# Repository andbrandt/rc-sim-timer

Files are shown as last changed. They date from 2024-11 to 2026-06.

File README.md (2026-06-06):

rc-sim-timer
===
Project to manage RC Flight Simulators via an Arduino-based push button UI.



Currently supported RC FLight Simulators:

* Phoenix v4
* RealFlight Basic
* RealFlight v9

    Note: This project uses git submodules.

    To clone this project use these commands:

    * git clone https://github.com/andbrandt/rc-sim-timer
    * cd rc-sim-timer
    * git submodule init
    * git submodule update

---
# Features:

* Pushbutton to reset simulation when plane gets too far away - or crashes
* Countdown on 7 segment display to show remaining time
* Flashing of 7 segment display when time is running out
* Cool-down period (8 seconds) to nudge current user to hand over controller to next person
* Long-press to select actual RC Simulator and simulation time of 2, 5 or 10 minutes
* Double-press to toggle between EASY and ACRO models

---
# How to start up system:

1. Start up Windows and log in
2. Connect USB RC controller to the front port of the sim-timer box
3. Connect the sim-timer box cable

---
# User Interface:

## Push button
* <b>Light in button</b>: Simulation ready to run - or running. 
* <b>Short-press</b>: Reset simulation
* <b>Double-press</b>: Toggle between EASY and ACRO models
* <b>Long-press</b>:  Enter Setup menu to select RC Simulator and simulation time.
  * Short-press while in Setup: Toggle selection
  * Long-press while in Setup: Accept current selection; then step to next setting or exit setup
* <b>Press during power-op</b>: SAFE MODE:
USB Keyboard/mouse inactivated to not interfere with firmware update

## 7-segment display
* Shows remaining simulation time
* In Setup menu, the display steps through options to be selected

---
# Simulator preparation
Depending on your simulator, you may have to do a litte setup to make it work with rc-sim-timer.
## Phoenix v4
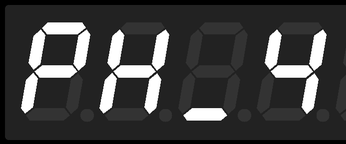
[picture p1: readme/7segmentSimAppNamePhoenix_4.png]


Define two airplane favorites in the aircraft setup menu. Let the first (uppermost) be an electric high-wing beginner model and the second be an aerobatic model.

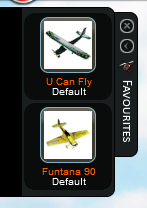
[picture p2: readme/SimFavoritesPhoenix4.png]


rc-sim-timer starts up the simulator when the USB plug is inserted.

TODO: Update code to select desired airport when starting.

TODO: Update code to select desired airplanes for easy and acro without requiring sim setup.

rc-sim-timer will choose an airplane from this list when you toggle between models using double press.
## RealFlight Basic
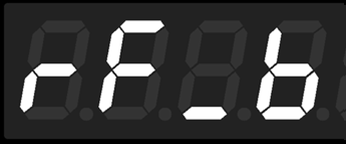
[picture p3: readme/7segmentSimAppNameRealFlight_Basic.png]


No preparations needed.

rc-sim-timer restores default settings and starts up the simulator when the USB plug is inserted.

## RealFlight v9
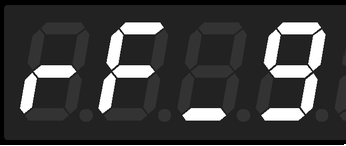
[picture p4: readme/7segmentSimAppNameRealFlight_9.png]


No preparations needed.

rc-sim-timer selects the same airport as in RealFlight Basic and starts up the simulator when the USB plug is inserted.

# Building the mechanics

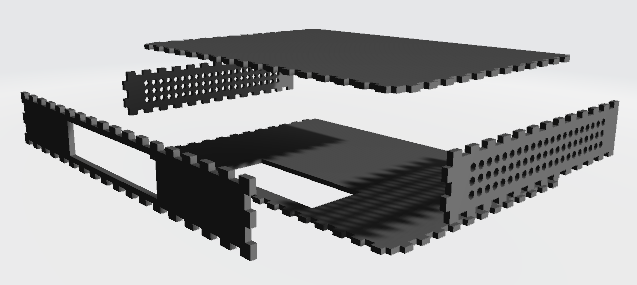
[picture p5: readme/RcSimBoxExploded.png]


## Bill of Material (BOM)

* Laser cut 6mm plywood components for enclosure (Link to design & files)
* 3D printed UI panel (Link to design & files)
* Arduino Pro Micro
* Push button with built-in light for UI effects (TODO: Link)
* 4-digit 7-segment I2C display
* Micro USB hub PCB (TODO: Link)
* Female USB connector

## Mounting electronics in the 3D printed UI panel

Start gluing the push button, arduino and USB connector into the recesses of the front panel. Push the two mounting rods sideways in to lock the USB connector into position.

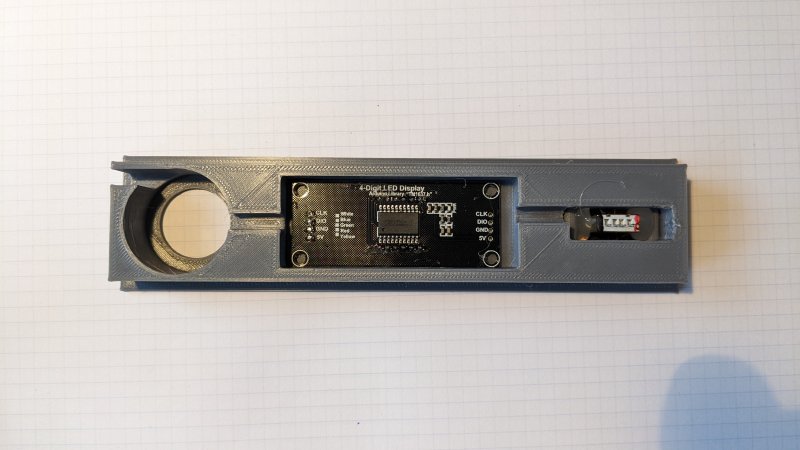
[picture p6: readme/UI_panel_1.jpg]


TODO

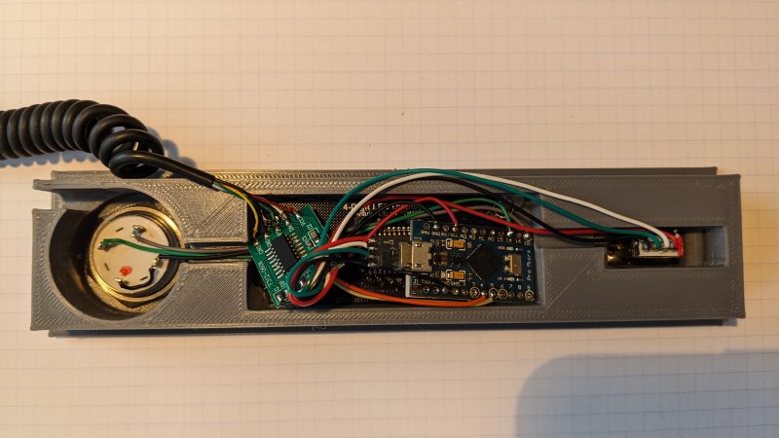
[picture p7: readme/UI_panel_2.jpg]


TODO

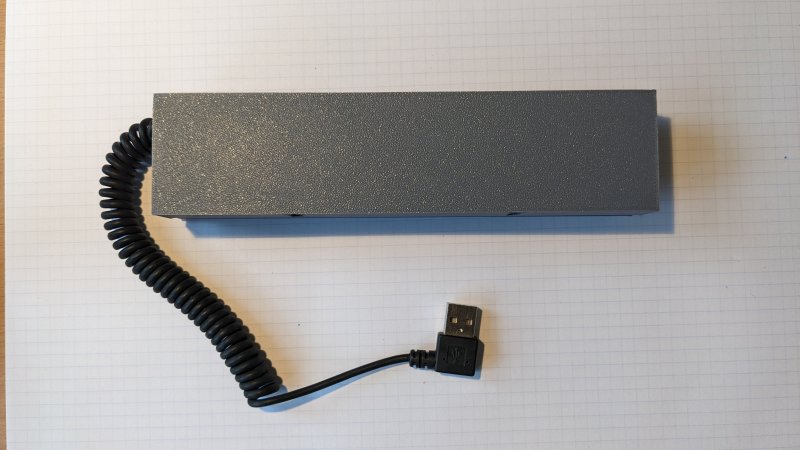
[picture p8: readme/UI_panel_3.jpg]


TODO

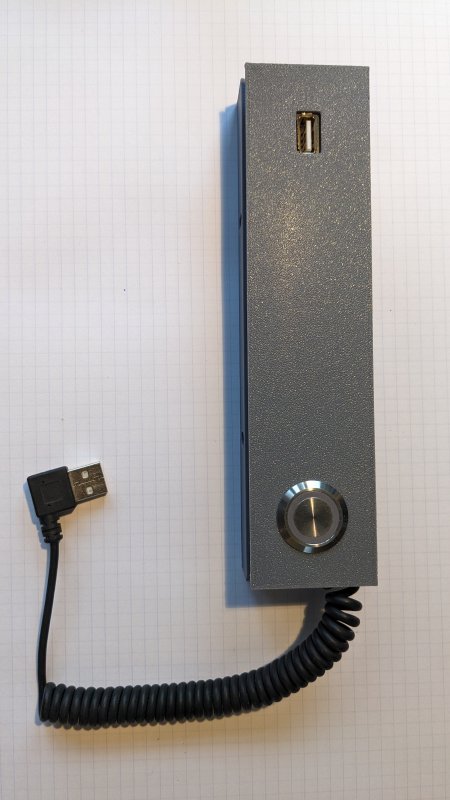
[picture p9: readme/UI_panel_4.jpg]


---
**WARNING #1**

When connecting the Arduino Pro Micro, it may show up as "Arduino Leonardo" or "LilyPad Arduino USB".

**DO NOT** change the board type in the Arduino IDE. You may brick the device (in a soft way),requiring you to reset the bootloader by double-resetting and loading an empty sketch to the device. 

**WARNING #2**

The push button (two individual items) used in this project was found to have + and - swapped...
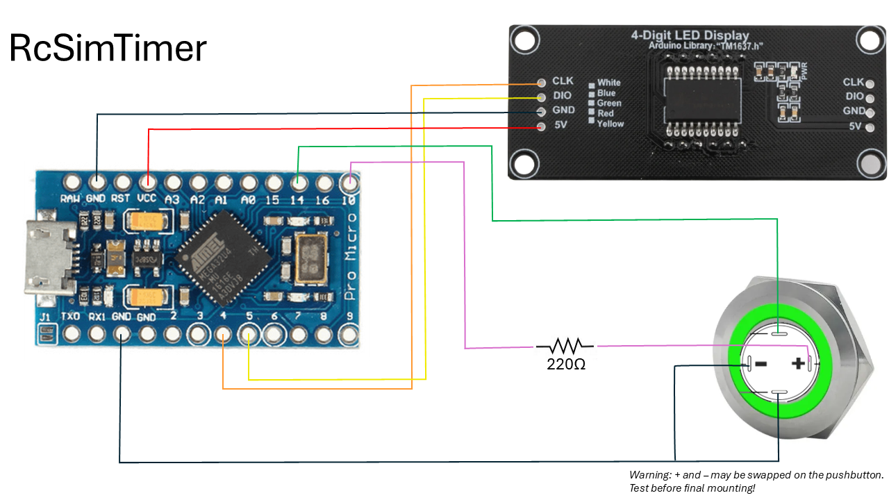
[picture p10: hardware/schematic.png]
Schematic


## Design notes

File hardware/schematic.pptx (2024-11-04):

## RcSimTimer

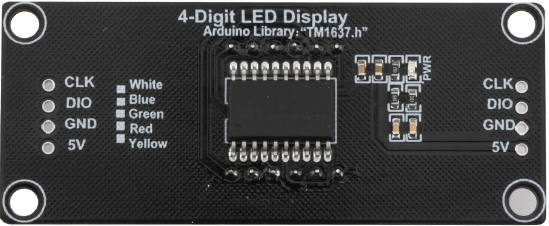
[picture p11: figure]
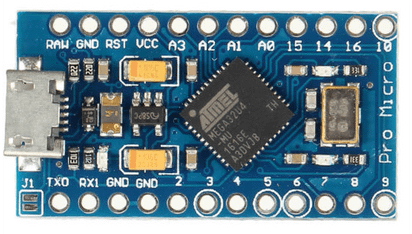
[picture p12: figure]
r/arduino - I need help wiring the pins on my pro micro. The pins are labelled different from what KBfirmware says, I'm not sure how to wire mine. Any help would be greatly appreciated.
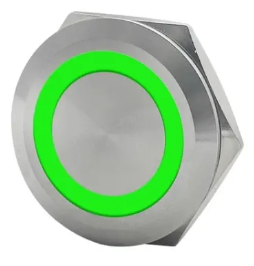
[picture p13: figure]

Warning: + and – may be swapped on the pushbutton.
Test before final mounting!

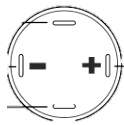
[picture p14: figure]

220Ω

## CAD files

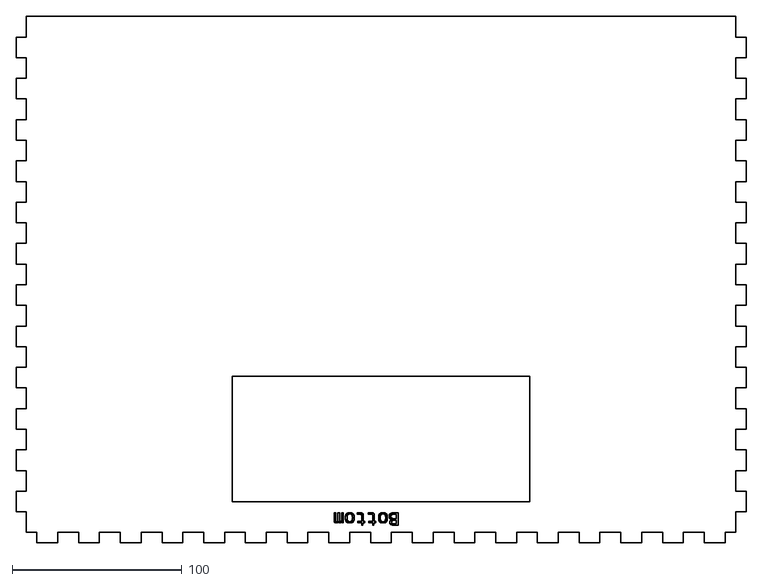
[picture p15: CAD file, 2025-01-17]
mechanics/box/RcSimBox_bottom.dxf
430.0 x 310.0

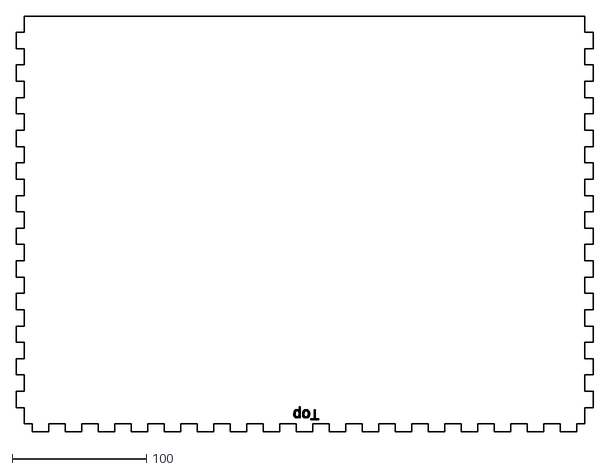
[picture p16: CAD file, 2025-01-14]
mechanics/box/RcSimBox_top.dxf
430.0 x 310.0

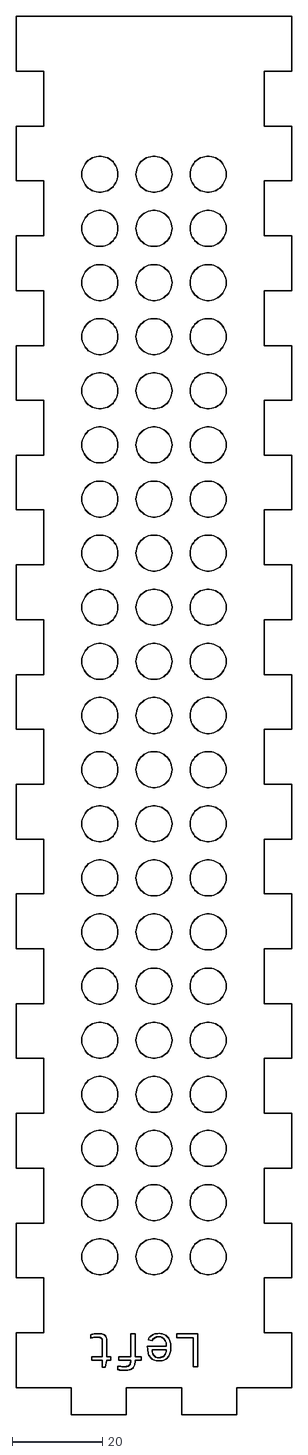
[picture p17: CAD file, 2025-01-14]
mechanics/box/RcSimBox_left.dxf
61.0 x 310.0

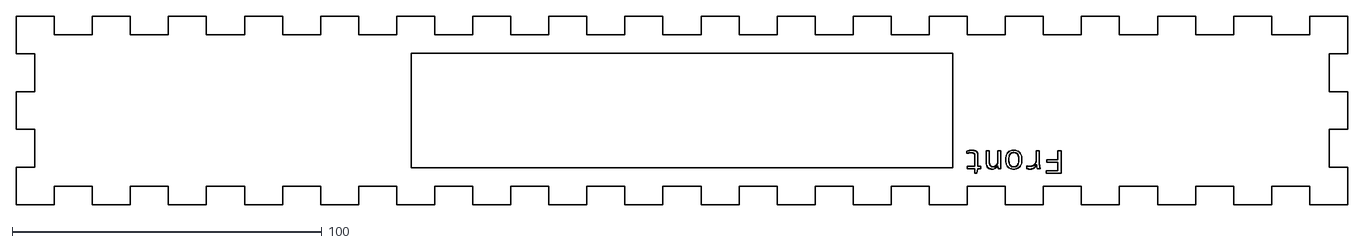
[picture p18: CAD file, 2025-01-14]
mechanics/box/RcSimBox_front.dxf
430.0 x 61.0

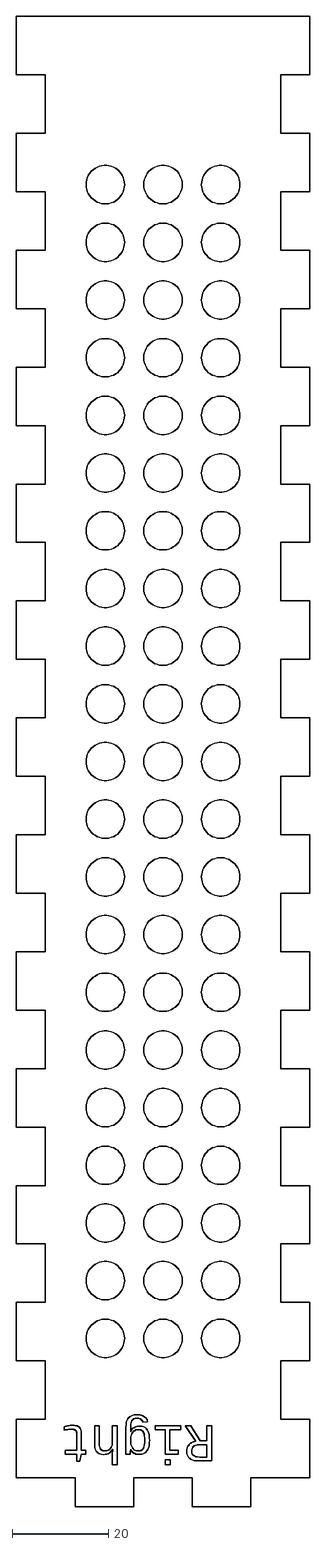
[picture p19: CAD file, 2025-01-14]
mechanics/box/RcSimBox_right.dxf
61.0 x 310.0

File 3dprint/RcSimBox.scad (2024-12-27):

$fn=50;

// Tricks to cut objects in LightBurn larger than physical laser bed:
// 1: https://www.youtube.com/watch?v=n__saOKVupA
// 2: https://www.youtube.com/watch?v=U259xw-fxOI
//
// Alternatives including making alignment holes and insert dowels after cutting first part

// Tricks to make STL to PNG: (Alternative: Make SCAD Projection cut and export to DXF for another lightburn layer)
// A: https://fenrus75.github.io/FenrusCNCtools/javascript/stl2png.html
//

axisX = 1;
axisY = 2;
axisZ = 3;

innerFinger = 0;
outerFinger = 1;

// Reference system:
// Outer box bottom resides on z=0 plane
// Outer box front is aligned to x axis (y=0) and symmetrical to y axis

boxOuterWidth           = 430;  // x
boxOuterDepth           = 310;  // y
boxOuterHeight          = 50;   // z
labelFontSize           = 8;

//boxOuterWidth           = 80;  // x
//boxOuterDepth           = 60;  // y
//boxOuterHeight          = 30;   // z
//labelFontSize           = 5.5;

materialThickness       = 6;    // Thickness of the board
fingerDepth             = materialThickness;    // Must always match
fingerTargetWidth       = fingerDepth*2;   // Actual width Must be calculated to match the actual edge length; Never to be less than this number
fingerCutCompensation   = 0; // -0.5;    // Makes cutting tool remove a little less (or add if negative) from all edges

airHoleDiameter         = 8;
airHoleSpacing          = 12;

//boxInnerWidth           = boxOuterWidth - materialThickness*2;
//boxInnerDepth           = boxOuterDepth - materialThickness;
//boxInnerHeight          = boxOuterHeight - materialThickness*2;

sideOffsetLeft          = (boxOuterWidth-materialThickness)/2;
sideOffsetRight         = -sideOffsetLeft;
sideOffsetTop           = (boxOuterHeight - materialThickness)/2;
sideOffsetBottom        = -sideOffsetTop;
sideOffsetFront         = (-boxOuterDepth + materialThickness)/2;

timerFrameWidth         = 175;
timerFrameHeight        = 37;

// #################### BASIC BOX SHAPE ###########################

module Layer01_BoxSolid()
{    
//    translate([0,boxOuterDepth/2,boxOuterHeight/2])
    cube([boxOuterWidth,boxOuterDepth,boxOuterHeight], center=true);
}

module Layer03_BoxCutoutTimerFrame()
{        
//    translate([0,boxOuterDepth/2,boxOuterHeight/2]) 
    cube([timerFrameWidth,boxOuterDepth+0.01,timerFrameHeight], center=true);
}

module Layer04_BoxCutoutAirHoles()
{        
holeStepRangeY = floor((boxOuterDepth - airHoleSpacing*4)/(airHoleSpacing*2))*2;
holeStepRangeZ = floor((boxOuterHeight - airHoleSpacing*2)/(airHoleSpacing*2))*2;

    for (StepY = [-holeStepRangeY/2:holeStepRangeY/2])
    {
        for (StepZ = [-holeStepRangeZ/2:holeStepRangeZ/2])
        { 
            translate([0,StepY*airHoleSpacing,StepZ*airHoleSpacing]) rotate([0,90,0,]) cylinder(d=airHoleDiameter, h=boxOuterWidth+0.01, center=true);
        }    
    }
}

module Layer09_BoxWithCutouts()
{
    difference() {
        Layer01_BoxSolid();
        Layer03_BoxCutoutTimerFrame();
        Layer04_BoxCutoutAirHoles();
    }
}

// #################### ISOLATED BOX SIDES###########################

module Layer11_SideLeft()
{    
    intersection() {
        Layer09_BoxWithCutouts();
        translate([-sideOffsetLeft,0,0]) cube([materialThickness,boxOuterDepth*2,boxOuterHeight*2], center=true);
    }
}

module Layer12_SideRight()
{    
    intersection() {
        Layer09_BoxWithCutouts();
        translate([+sideOffsetLeft,0,0]) cube([materialThickness,boxOuterDepth*2,boxOuterHeight*2], center=true);
    }
}

module Layer13_SideTop()
{    
    intersection() {
        Layer09_BoxWithCutouts();
        translate([0,0,sideOffsetTop]) cube([boxOuterWidth*2,boxOuterDepth*2,materialThickness], center=true);
    }
}

module Layer14_SideBottom()
{    
    intersection() {
        Layer09_BoxWithCutouts();
        translate([0,0,sideOffsetBottom]) cube([boxOuterWidth*2,boxOuterDepth*2,materialThickness], center=true);
    }
}

module Layer15_SideFront()
{    
    difference() {
        intersection() {
            Layer09_BoxWithCutouts();
            translate([0,sideOffsetFront,0]) cube([boxOuterWidth*2,materialThickness,boxOuterHeight*2], center=true);
        }
        
    }
}

//module Layer19_AllSides()   // Just for testing. No need for finger cutting
//{    
//    Layer11_SideLeft();
//    Layer12_SideRight();
//    Layer13_SideTop();
//    Layer14_SideBottom();
//    Layer15_SideFront();
//}

// #################### FINGER MARKERS ###########################
function fingerNumber(edgeLength) = 2*floor(edgeLength/(fingerTargetWidth*2))+1; // Must be an odd number!

function fingerWidth(edgeLength) = edgeLength/fingerNumber(edgeLength);

module FingerMarkers(axis, edgeLength, innerOuterFinger)
{
    rotate(axis == axisZ ? [0,-90,0] : (axis == axisY ? [0,0,90] : [0,0,0])) {
        for (finger = [innerOuterFinger:2:fingerNumber(edgeLength)-1])
        {
            translate([(finger+0.5)*fingerWidth(edgeLength)-edgeLength/2,0,0]) cube([fingerWidth(edgeLength)-fingerCutCompensation+0.01,fingerDepth-fingerCutCompensation+0.01,fingerDepth-fingerCutCompensation+0.01], center=true);
        }
    }
}

module Layer21_SideLeftWithFingers()
{
    difference() {
        Layer11_SideLeft();

        // Front edge
        translate([(-boxOuterWidth+fingerDepth)/2,sideOffsetFront,0]) FingerMarkers(axisZ, boxOuterHeight, innerFinger);

        // Side edges
        for (zPos=[-sideOffsetTop, +sideOffsetTop]) {
            translate([(-boxOuterWidth+fingerDepth)/2,fingerDepth/2,zPos]) FingerMarkers(axisY, boxOuterDepth-fingerDepth, outerFinger);
        }
    }
}

module Layer22_SideRightWithFingers()
{
     translate([boxOuterWidth-materialThickness,0,0]) Layer21_SideLeftWithFingers();    
}

module Layer23_SideTopWithFingers()
{        
    difference() {
        Layer13_SideTop();

        // Front edge
        translate([0,sideOffsetFront,(boxOuterHeight-materialThickness)/2]) FingerMarkers(axisX, boxOuterWidth, innerFinger);

        // Side edges
        for (edgeFactor=[-1:2:+1]) {
            translate([edgeFactor*(boxOuterWidth-fingerDepth)/2,fingerDepth/2,(boxOuterHeight-fingerDepth)/2]) FingerMarkers(axisY, boxOuterDepth-fingerDepth, innerFinger);
        }
    }
}

module Layer24_SideBottomWithFingers()
{     
     translate([0,0,-(boxOuterHeight-materialThickness)]) Layer23_SideTopWithFingers();
}

module Layer25_SideFrontWithFingers()
{        
    difference() {
        Layer15_SideFront();
        
        // Bottom and Top edges
        for (edgeFactor=[-1,+1]) {
            translate([0,sideOffsetFront,edgeFactor*(boxOuterHeight-fingerDepth)/2]) FingerMarkers(axisX, boxOuterWidth, 
                outerFinger);
        }        
        
        // Left and Right edges
        for (edgeFactor=[-1,+1]) {
            translate([edgeFactor*(boxOuterWidth-fingerDepth)/2,sideOffsetFront,0]) FingerMarkers(axisZ, boxOuterHeight, outerFinger);
        }
    }
}

// ###############################################
module SideName(sideName) {
    color("DimGray") translate([-16,0,-boxOuterWidth*0.75]) linear_extrude(height = boxOuterWidth) text(sideName, font = "Liberation Mono", size = labelFontSize, valign = "center");
}

module Layer31_SideLeftFlattened()
{     
    projection(cut = false)
    difference() {
        rotate([0,-90,0]) Layer21_SideLeftWithFingers();
    translate([-5,-boxOuterDepth/2+14,0]) rotate([0,0,180]) SideName("Left");
    }
}

module Layer32_SideRightFlattened()
{     
    projection(cut = false)
    difference() {
        rotate([0,90,0]) Layer22_SideRightWithFingers();
    translate([-5,-boxOuterDepth/2+14,0]) rotate([0,0,180]) SideName("Right");
    }    
}

module Layer33_SideTopFlattened()
{     
    projection(cut = false)
    difference() {
        rotate([0,180,0]) Layer23_SideTopWithFingers();
    translate([-5,-boxOuterDepth/2+14,0]) rotate([0,0,180]) SideName("Top");
    }    
}

module Layer34_SideBottomFlattened()
{     
    projection(cut = false)
    difference() {
        Layer24_SideBottomWithFingers();
    translate([-5,-boxOuterDepth/2+14,0]) rotate([0,0,180]) SideName("Bottom");
    }    
}

module Layer35_SideFrontFlattened()
{     
    projection(cut = false)
    difference() {
        rotate([90,0,0]) Layer25_SideFrontWithFingers();
    translate([boxOuterWidth*0.25,-boxOuterHeight/2+14,0]) rotate([0,0,180]) SideName("Front");
    }    
}

sideToFlatten = "None";
echo(sideToFlatten);
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

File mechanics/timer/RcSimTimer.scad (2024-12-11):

$fn=100;

frameFrontThickness = 2;
frameFrontOverlap   = 8;
frameWallThickness  = 2;

usbFrontWidth        = 31;
usbFrontHeight       = 10;
usbFrontDepth        = 1.7;

usbBaseWidth            = 13;
usbBaseHeight           = 7;
usbBaseDepth            = 19;

usbFrontOffset      = 0;

UsbMountThingyWidth = 5;
UsbMountThingyHeight = UsbMountThingyWidth*1.5;

displayWidth        = 51;
displayHeight       = 20;
displayDepth        = 8;

displayBaseWidth    = 72;
displayBaseHeight   = 28;
displayBaseDepth    = usbBaseDepth;

displayFrontOffset  = frameFrontThickness-0.4;


buttonDiameterTop   = 20;
buttonDiameterBottom= 25;
buttonDepth         = 2;

buttonBaseDiameter  = 23;
buttonBaseDepth     = usbBaseDepth;

buttonFrontOffset   = frameFrontThickness;


frameBaseWidth      = displayWidth*2+usbBaseWidth*2+buttonDiameterBottom*2-4;
frameBaseHeight     = displayHeight*2-4;
frameBaseDepth      = usbBaseDepth-frameFrontThickness-0.1;

frameWidth          = frameBaseWidth+frameFrontOverlap;
frameHeight         = frameBaseHeight+frameFrontOverlap;
frameDepth          = frameFrontThickness;

/*

frameBaseWidth      = frameWidth-4;
frameBaseHeight     = frameHeight-4;
frameBaseDepth      = usbBaseDepth-frameFrontThickness-0.1;

frameWidth          = displayWidth*2+usbBaseWidth*2+buttonDiameterBottom*2;
frameHeight         = displayHeight*2;
frameDepth          = frameFrontThickness;
*/


//usbThingyWidth = usbFrontHeight*0.6;
//usbThingyBridgeHeight = usbBaseHeight*4;
//usbThingyContactDepth = frameBaseDepth/2 - usbFrontDepth;

usbXcenterPos = -displayBaseWidth+5;

module Layer01a_UsbMountThingy()
{    
    translate([0,0,-UsbMountThingyWidth/2]) cube([UsbMountThingyWidth,frameBaseHeight+0.01,UsbMountThingyWidth], center=true);

    translate([0,0,+UsbMountThingyWidth/2-UsbMountThingyHeight]) rotate([90,0,0]) cylinder(h=frameBaseHeight+0.01, d=UsbMountThingyWidth, center=true);
}

module Layer01b_UsbMountThingies(distance,scale) 
{
    for(xPos = [-distance/2, +distance/2]) {
        translate([xPos,0,usbFrontOffset-usbFrontDepth])scale([scale,1,scale])
Layer01a_UsbMountThingy();        
    }
}

module Layer01c_UsbMountThingiesFitSelection() 
{
    for(count = [3,4,5,6,7]) {
        translate([UsbMountThingyWidth*(count-4)*2.5,0,usbFrontOffset])Layer01b_UsbMountThingies(0, (UsbMountThingyHeight-count*0.1)/UsbMountThingyHeight);
    }
}

module Layer01_UsbCutout()
{
    color("green") {    
    
        // Frame cutout
        translate([0,0,+usbBaseDepth/2-0.01]) cube([usbBaseWidth+2, usbBaseHeight+2, usbBaseDepth], center=true);
    
        // Device base
        translate([0,0,-usbBaseDepth/2]) cube([usbFrontWidth+0.25, usbFrontHeight+0.25, usbBaseDepth], center=true);

    translate([0,0,usbFrontOffset])Layer01b_UsbMountThingies(usbFrontWidth-UsbMountThingyWidth, 1);
    }    
}

module Layer02_DisplayCutout()
{
    color("red") {
//        // Frame cutout
//        translate([0,0,+displayDepth/2-0.01]) cube([displayWidth-2, displayHeight-2, displayDepth], center=true);
        
        // Actual display
        translate([0,0,-displayDepth/2]) cube([displayWidth, displayHeight, displayDepth], center=true);

        // Display base
        translate([0,0,-displayDepth-displayBaseDepth/2+0.01]) cube([displayBaseWidth, displayBaseHeight, displayBaseDepth], center=true);
    }
}

module Layer03_PushbuttonCutout()
{
    color("blue") {    
        // Actual button
        translate([0,0,+buttonDepth/2]) cylinder(h=buttonDepth, d1=buttonDiameterBottom, d2=buttonDiameterTop, center=true);

        // Button base
        translate([0,0,-buttonBaseDepth/2+0.01]) cylinder(h=buttonBaseDepth, d=buttonBaseDiameter, center=true);
        
        // Button base mount space
        translate([0,0,-frameFrontThickness-buttonBaseDepth/2+0.01]) cylinder(h=buttonBaseDepth, d=frameBaseHeight-frameWallThickness*2, center=true);
        
    }
}
    
module Layer09_FullUiCutout()
{
    translate([+displayBaseWidth-5,0,buttonFrontOffset+0.01]) Layer03_PushbuttonCutout();
    translate([0,0,displayFrontOffset+0.01]) Layer02_DisplayCutout();
    translate([usbXcenterPos,0,usbFrontOffset]) Layer01_UsbCutout();    
}


module Layer10_FrameSolid(adder)
{
    scale([(frameBaseWidth+adder)/frameBaseWidth, (frameBaseHeight+adder)/frameBaseHeight, (frameBaseDepth+adder)/frameBaseDepth]) {
        // Actual Frame
        translate([0,0,+frameDepth/2]) cube([frameWidth, frameHeight, frameDepth], center=true);

        // Frame base
        translate([0,0,-frameBaseDepth/2]) cube([frameBaseWidth, frameBaseHeight, frameBaseDepth], center=true);
    }    
}

module Layer11_BackCoverStripHoleCutout(depth)
{
    for(xPos = [-displayBaseWidth-10, +displayBaseWidth+10]) {
        hull() {
            translate([xPos/2,0,-UsbMountThingyWidth/2]) rotate([90,0,0]) cylinder(d=UsbMountThingyWidth, h=frameBaseHeight+10, center=true);
            translate([xPos/2,0,-UsbMountThingyWidth/2-depth]) rotate([90,0,0]) cylinder(d=UsbMountThingyWidth, h=frameBaseHeight+10, center=true);
        }
    }
}

module Layer11b_FrameStripHoleCutout()
{
angleSpan = 45;
extrudeRadius = 100;
    
    for(xPos = [-displayBaseWidth-10, +displayBaseWidth+10]) {
        translate([xPos/2,0,-UsbMountThingyWidth*1.5])
        rotate([0,-90,0]) translate([-extrudeRadius, 0, 0]) scale([1,0.5,1]) rotate([0,0,-angleSpan/2]) rotate_extrude(angle=angleSpan, convexity=10)
       translate([extrudeRadius, 0]) circle(d=UsbMountThingyWidth);
    }
}

module Layer12_BackCoverCableHoleCutout(depth, length)
{
    hull() {
        translate([0,0,0]) rotate([0,90,0]) cylinder(d=UsbMountThingyWidth, h=length, center=true);

    translate([0,0,0-depth]) rotate([0,90,0]) cylinder(d=UsbMountThingyWidth, h=length, center=true);
    }
}


module Layer19_FinalFrame()
{
    difference() {
        Layer10_FrameSolid(0);
        Layer09_FullUiCutout();
//        translate([0,0,-UsbMountThingyWidth*1.0])Layer11_BackCoverStripHoleCutout(0);
        translate([0,0,+1])Layer11b_FrameStripHoleCutout();
        color("chocolate")         translate([+frameBaseWidth*0.5,frameBaseHeight*0.37,-UsbMountThingyWidth/2-3]) Layer12_BackCoverCableHoleCutout(12,frameBaseWidth/5);

    color("aqua")         translate([+frameBaseWidth*0.25,0,-UsbMountThingyWidth*2.5]) Layer12_BackCoverCableHoleCutout(7,frameBaseWidth/5);

    color("lime")         translate([-frameBaseWidth*0.25,frameBaseHeight*0.07,-UsbMountThingyWidth*2.5]) Layer12_BackCoverCableHoleCutout(7,frameBaseWidth/5);
    }
}

module Layer20_BackCover()
{
    difference() {
        translate([0,0,-(frameBaseDepth+frameWallThickness)/2]) cube([frameWidth, frameHeight, frameBaseDepth+frameWallThickness], center=true);
        translate([0,0,+0.01]) Layer10_FrameSolid(1.0);
        translate([0,0,-UsbMountThingyWidth*0.6]) Layer11_BackCoverStripHoleCutout(8);
        color("chocolate")         translate([+frameBaseWidth*0.5,frameBaseHeight*0.37,-UsbMountThingyWidth/2+2+4]) Layer12_BackCoverCableHoleCutout(10,frameBaseWidth/5);

    }
}

partToRender = "FrontPanel";
echo(partToRender);

if (partToRender == "FrontPanel")
    Layer19_FinalFrame();
if (partToRender == "BackCover")
    Layer20_BackCover();
if (partToRender == "UsbSpikes")
    Layer01c_UsbMountThingiesFitSelection();
//endif)

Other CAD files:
mechanics/box/RcSimBox.scad

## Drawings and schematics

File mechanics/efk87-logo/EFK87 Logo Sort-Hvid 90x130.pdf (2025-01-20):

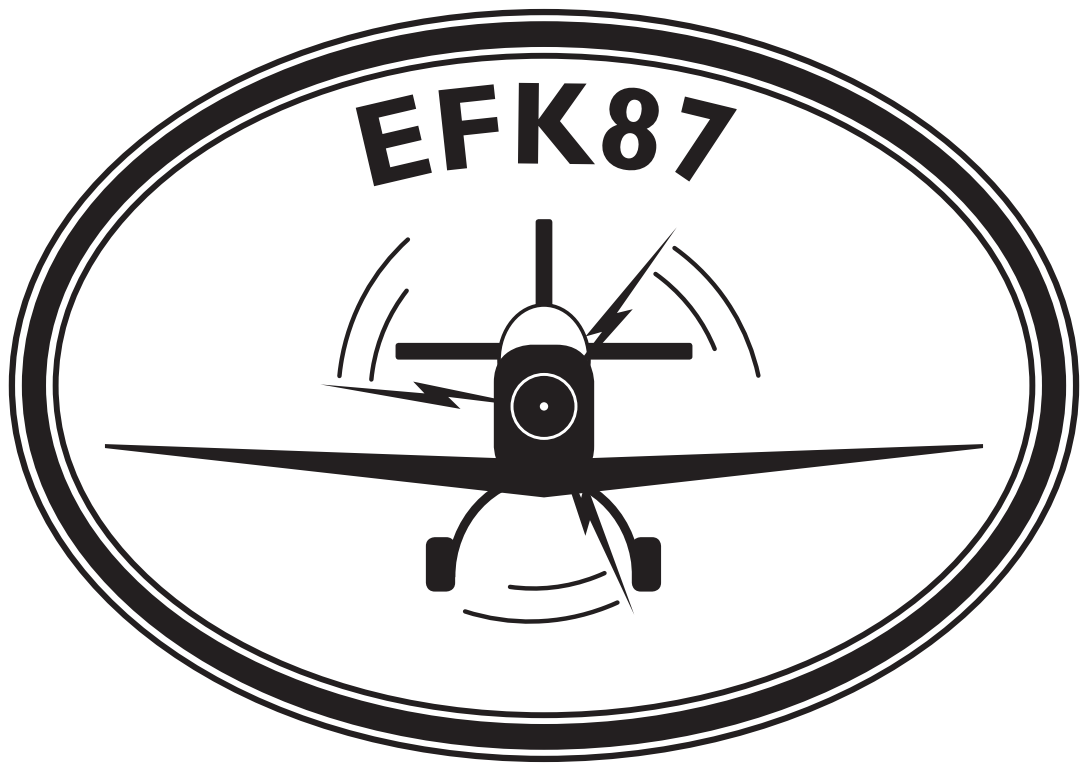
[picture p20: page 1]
EFK87

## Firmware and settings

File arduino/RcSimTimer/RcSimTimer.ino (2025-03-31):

//#define DEBUG
#include "src/anduinolib/debug/Debug.hpp"

#include <Arduino.h>

#include "src/anduinolib/ui/Display7Seg.hpp"
#include "src/anduinolib/ui/LED.hpp"
#include "src/anduinolib/ui/LedPushButton.hpp"
#include "src/anduinolib/io/usb-hid/KeyboardCtl.hpp"
//#include "src/anduinolib/io/usb-hid/MouseCtl.hpp"
#include "src/anduinolib/sys/Time.hpp"

#include "hal.hpp"
#include "UiEvent.hpp"
#include "UI.hpp"

using namespace anduinolib::sys;
using namespace anduinolib::io::usbHid;
using namespace anduinolib::ui;

Display7Seg   display7Seg(DISPLAY_7SEG_PIN_CLK, 
                          DISPLAY_7SEG_PIN_SDA, 
                          DISPLAY_7SEG_LIGHT_LEVEL_OFF, 
                          DISPLAY_7SEG_LIGHT_LEVEL_ON);

LED           ledPcb(     ONBOARD_LED_PIN, 
                          ONBOARD_LED_LEVEL_OFF, 
                          ONBOARD_LED_LEVEL_ON);

LedPushButton ledPushButton(PUSHBUTTON_PIN_LED, 
                          PUSHBUTTON_LED_LEVEL_OFF, 
                          PUSHBUTTON_LED_LEVEL_ON, 
                          PUSHBUTTON_PIN_SWITCH);
UI            ui;

void setup() 
{
  bool safeMode = true;

  DEBUG_SETUP();  // <- Uncomment #define DEBUG in first line of this file (RcSimTimer.ino) to enable debug printing in ALL project files
  time.Begin();

  display7Seg.Begin();
  ledPcb.Blink(true, 250, 250);

  safeMode = ledPushButton.Begin(&ui, UiEvent::Setup, UiEvent::Enter, UiEvent::ModelToggle);

  if (safeMode) {
    DEBUG_PRINT("SafeMode");  
  }
  KeyboardCtl::Begin(!safeMode);
  ui.Begin(&display7Seg, &ledPushButton, safeMode);
}

void loop() 
{
  time.Poll();
  ui.Poll();
  display7Seg.Poll();
  ledPcb.Poll();
  ledPushButton.Poll();
}

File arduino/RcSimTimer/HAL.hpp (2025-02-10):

#ifndef HAL_h
#define HAL_h

// Defines for PCB
#define ONBOARD_LED_PIN 17
#define ONBOARD_LED_LEVEL_ON 0
#define ONBOARD_LED_LEVEL_OFF 255

// Defines for 7 segment display
#define DISPLAY_7SEG_PIN_CLK 4
#define DISPLAY_7SEG_PIN_SDA 5
#define DISPLAY_7SEG_LIGHT_LEVEL_ON 75
#define DISPLAY_7SEG_LIGHT_LEVEL_OFF 0

// Defines for pushbutton w. builtin LED
#define PUSHBUTTON_PIN_SWITCH 14
#define PUSHBUTTON_PIN_LED    10
#define PUSHBUTTON_LED_LEVEL_ON  255
#define PUSHBUTTON_LED_LEVEL_OFF 0

// Defines for joystick
#define JOYSTICK_PIN_BUTTON   PD6
#define JOYSTICK_PIN_AXIS_X   A0
#define JOYSTICK_PIN_AXIS_Y   A1

#endif

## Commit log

2024-11-04 First commit of Arduino code and 3D design file.
    [RcSimTimer.scad]
2024-11-04 Moved Schematic.pptx to hw folder
2024-11-04 Generated schematic .png file for Git README.md front page.
2024-11-04 added schematic .png file
2024-11-04 fighting some windows case issue...
2024-11-06 Add .stl file via upload
    [RcSimTimer.stl]
2024-11-06 Phoenix now correctly blocked after USB insertion and after setup menu
2024-11-07 Pin assignments and basic levels moved from Begin functions to constructors
2024-11-10 Fixed various time display issues
    [RcSimTimer.ino]
2024-11-12 added simulator 7segment identifiers
    [RcSimTimer.scad]
2024-11-15 moved anduinolib into arduino folder
2024-11-19 Completed 3D SCAD model and stl files
    [RcSimTimer.scad, RcSimTimer.stl, RcSimTimerBackCover.stl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]
2024-11-21 First real 3D candidate - minor tweaks pending
    [RcSimTimer.scad, RcSimTimer.stl, UsbThingies.stl]
2024-12-02 shapshot of laptop box design
    [RcSimBox.scad, RcSimTimer.scad]
2024-12-02 laptop box design almost complete. Inner air gap bottom rails still missing
    [RcSimBox.scad]
2024-12-03 Adjusted coordinate system to symmetric on all axis
    [RcSimBox.scad]
2024-12-05 Added label to box bottom. Text still missing on other sides. Lightburn project initiated but not completed
    [RcSimBox.scad]
2024-12-11 Added build script to generate all components for 3d print and laser cutting
    [RcSimBox.scad, RcSimTimer.scad, RcSimTimer.stl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]
2024-12-11 Re-introduced sides w. fingers for visual validation
    [RcSimBox.scad]
2024-12-27 minor cleanup; preparation for laser cut
    [RcSimBox.scad]
2024-12-27 .bat split into two separare .bats
    [RcSimBox.scad]
2024-12-27 Fixed merge conflict
    [RcSimBox.scad]
2024-12-27 Fixed airhole alignment bug
    [RcSimBox.scad]
2025-01-14 New structure for 3D elements. Almost complete Lightburn file
    [RcSimBox.scad, RcSimBox_bottom.dxf, RcSimBox_front.dxf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]
2025-01-17 minor improvements to simBox design and lasercut file. Added simulation bat+ini for RealFlightBasic support
    [RcSimBox.scad, RcSimBox_bottom.dxf]
2025-01-20 Box design and all laser files completed. First iteration of RealFlightBasic bat manipulation.
2025-02-10 Fixed debug printing only working in some files. Added SAFE MODE to prevent USB Keyboard noise during FW update
    [HAL.hpp, RcSimTimer.ino]
2025-03-31 Only light green button when start-up init sequence is really finished.
2025-04-06 Updated readme.MD: Intro, Ph4 section, exploded box view to mechanics.
    [RcSimBox.scad]
2026-06-06 Added details to readme.md.
    [RcSimBox.scad]
